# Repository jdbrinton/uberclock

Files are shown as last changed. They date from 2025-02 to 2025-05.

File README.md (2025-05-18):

# UberClock PCB
This is the PCB design for the Crystal Filter for the UberClock multi-mode oscillator.

To download gerber files, schematics, or other documentation, see [Latest Release](https://github.com/jdbrinton/uberclock/releases).

# Details
Board dimensions: 100x100mm

Tools: Altium Designer Professional (23.11.1)

# Errata
1. See [issue #1](https://github.com/jdbrinton/uberclock/issues/1) for details and resolution. Crystal resonator footprint wrong. Pin numbers are mirrored.

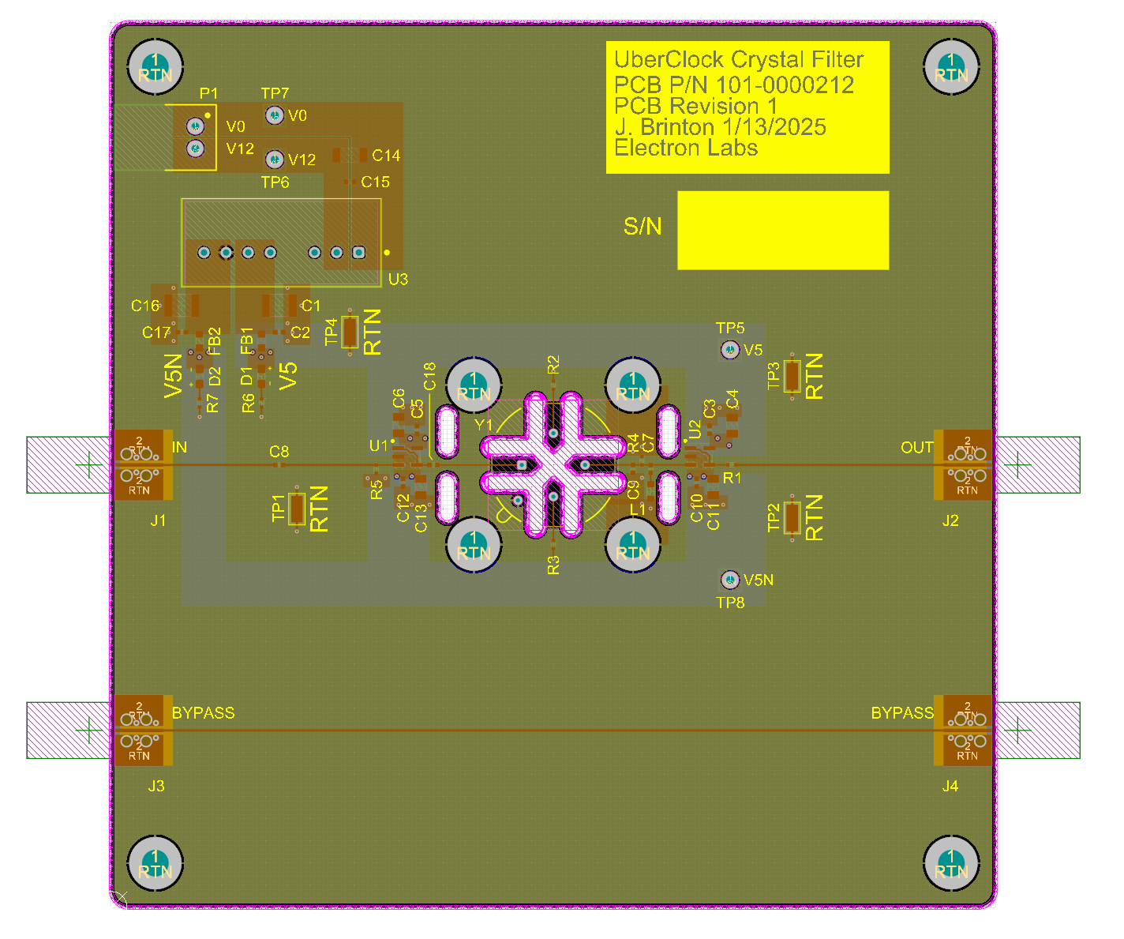
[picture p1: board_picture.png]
PCB Design

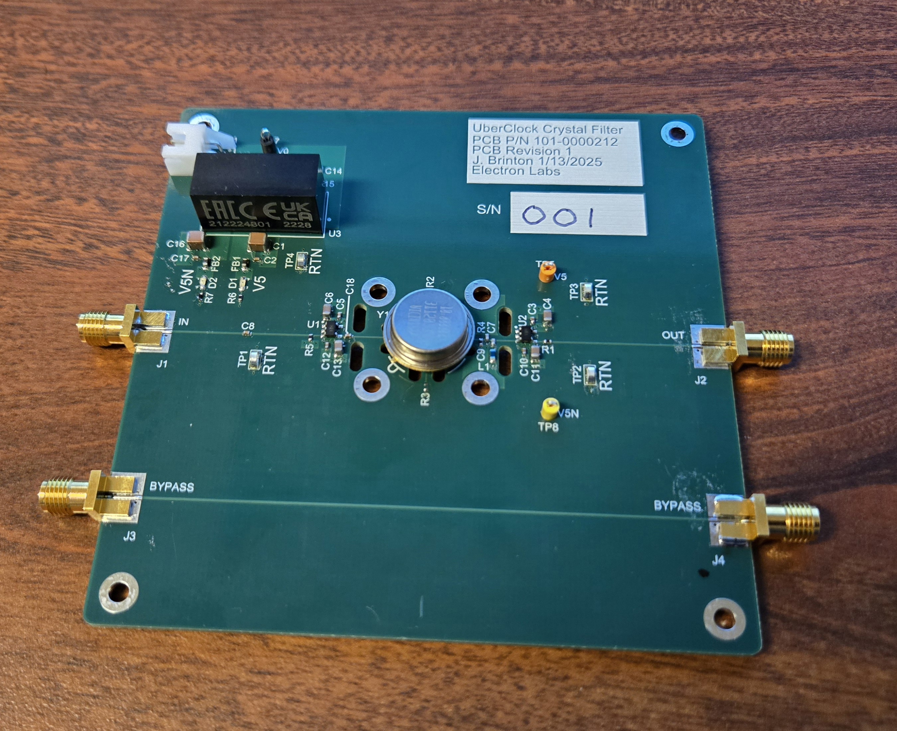
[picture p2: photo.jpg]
PCB Photo


# Measurements

Measurements taken on NanoVNA V2 (https://nanorfe.com/nanovna-v2.html)

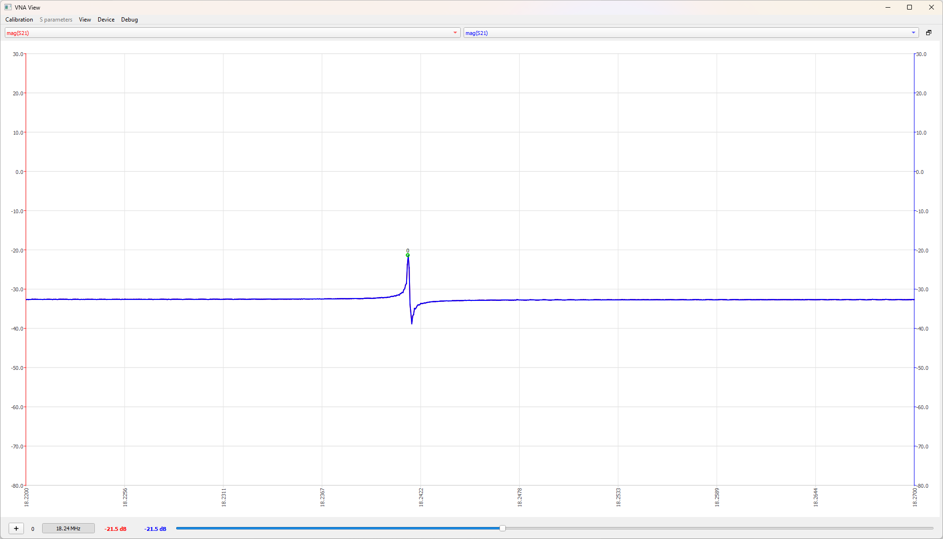
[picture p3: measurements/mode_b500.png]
Mode B500

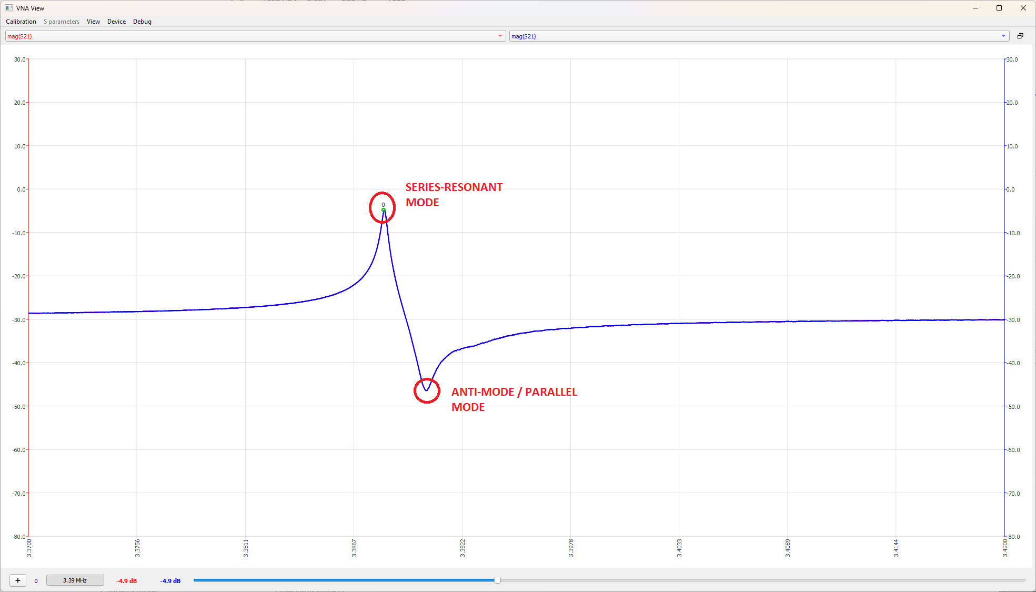
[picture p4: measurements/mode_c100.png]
Mode C100

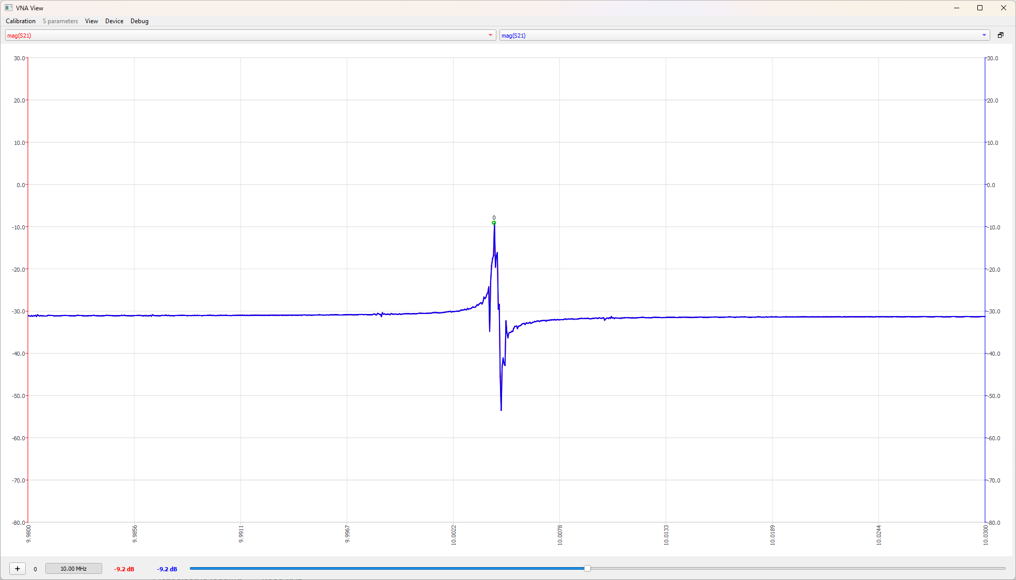
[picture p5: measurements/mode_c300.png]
Mode C300

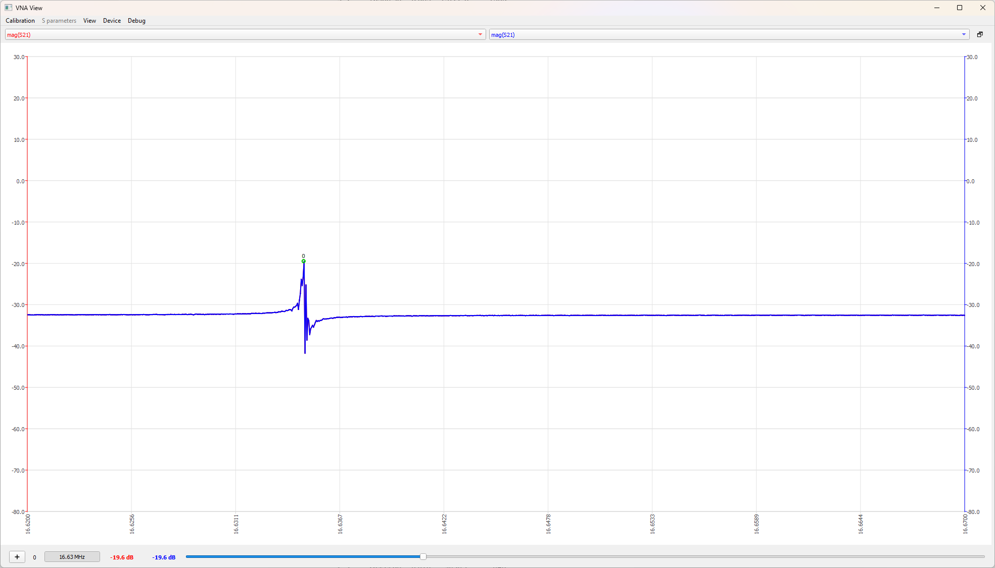
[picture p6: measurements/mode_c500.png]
Mode C500


# Sponsor

This work received donation from: https://nlnet.nl/project/uberClock/

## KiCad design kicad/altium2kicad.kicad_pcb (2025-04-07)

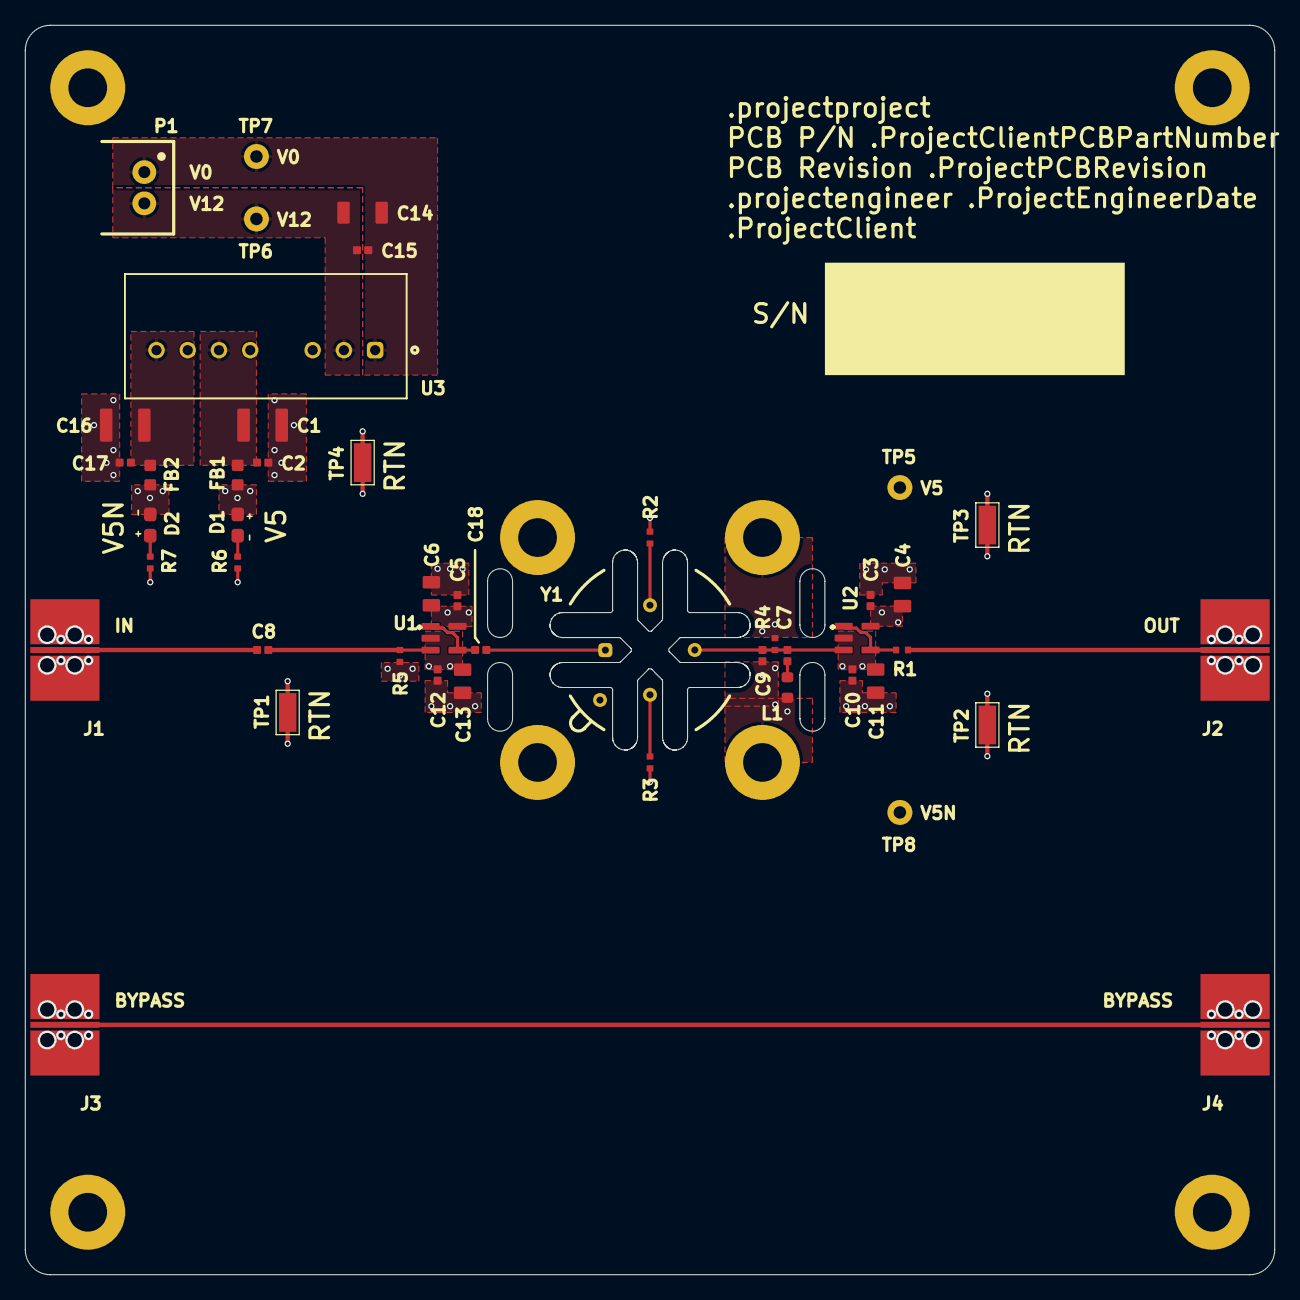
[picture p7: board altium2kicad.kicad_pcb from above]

Board: 4 copper layers, 100.0 x 100.0 mm, 55 parts (0 on the bottom side), 20 nets.

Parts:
C1, C16: CGA6P1X7S1A476M250AC; CAPC3225X25N
C2, C3, C5, C8, C10, C12, C15, C17, C18: CGA2B3X7R1V104K050BB; CAPC1005X05N
C4, C6, C11, C13: CGA4J3X5R1E475K125AB; CAPC2012X125N
C7, C9: CGA2B2C0G1H180J050BA; CAPC1005X05N
C14: CGA5L3X5R1V106M160AB; CAPC3216X16N
D1, D2: LTST-C191KGKT; 0603_LED
FB1, FB2: BLM18AG102SN1; INDC1608X08N
J1, J2, J3, J4: #NAME?; 901-10510-1
L1: LQW18AN68NJ00D; INDC1608X08N
M1, M2, M3, M4, M5, M6, M7, M8: MOUNTM3
P1: S2B-XH-A
R1, R5: ERJ-2RKF49R9X; RESC1005X035N
R2, R3, R4: ERJ-2RKF1004X; RESC1005X035N
R6, R7: ERJ-2RKF1001X; RESC1005X035N
TP1, TP2, TP3, TP4: 5015
TP5: #NAME?; 5003
TP6: #NAME?; 5000
TP7: #NAME?; 5001
TP8: #NAME?; 5004
U1, U2: AD8065ARTZ-REEL7; SOT23-5
U3: DPBW03F-05; SPBW03F-05_MWU
Y1: 311205346

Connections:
BYPASS: J3.1, J4.1
NetC1_2: C1.2, C2.1, FB1.1, U3.6
NetC7_1: C7.1, L1.1
NetC8_1: C8.1, R5.2, U1.3
NetC16_2: C16.2, C17.1, FB2.1, U3.8
NetD1_2: D1.2, R6.1
NetD2_1: D2.1, R7.1
NetR2_1: R2.1, Y1.2
NetR3_1: R3.1, Y1.4
RTN: C1.1, C2.2, C3.2, C4.1, C5.2, C6.1, C9.1, C10.2, C11.1, C12.2, C13.1, C16.1, C17.2, J1.2, J2.2, J3.2, J4.2, L1.2, M1.1, M2.1, M3.1, M4.1, M5.1, M6.1, M7.1, M8.1, R2.2, R3.2, R4.1, R5.1, R6.2, R7.2, TP1.1, TP2.1, TP3.1, TP4.1, U3.7, Y1.5
SIN: C8.2, J1.1
SIN_T: C18.2, U1.1, U1.4
SOUT: J2.1, R1.1
SOUT_T: R1.2, U2.1, U2.4
V0: C14.1, C15.2, P1.1, TP7.1, U3.1
V5: C3.1, C4.2, C5.1, C6.2, D1.1, FB1.2, TP5.1, U1.5, U2.5
V5N: C10.1, C11.2, C12.1, C13.2, D2.2, FB2.2, TP8.1, U1.2, U2.2
V12: C14.2, C15.1, P1.2, TP6.1, U3.2
XIN: C18.1, Y1.1
XOUT: C7.2, C9.2, R4.2, U2.3, Y1.3

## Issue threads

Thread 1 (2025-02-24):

Crystal Resonator Footprint Wrong

jdbrinton, 2025-02-24:
Crystal resonator footprint wrong. Pin numbers are mirrored. Can be fixed by either 1) if the crystal isn't yet installed, installing crystal at 90 degrees and connecting ground pin to closest mounting pad, or 2) if the crystal is already installed, jumpering pins 1 to 2 and 3 to 4 and removing R2 and R3.

Method 1:

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

Method 2:

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

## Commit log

2025-01-20 updated 3d model of resonator
    [101-0000212_UBERCLOCK_CRYSTAL_FILTER.PcbDoc, 101-0000212_UBERCLOCK_CRYSTAL_FILTER.PcbLib]
2025-04-07 converting to kicad
    [altium2kicad.kicad_pcb, altium2kicad.kicad_sch]
